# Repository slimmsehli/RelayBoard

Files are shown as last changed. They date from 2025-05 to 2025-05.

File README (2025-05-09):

🟢 4-Channel Relay Board with Opto-Isolation for Arduino/Raspberry Pi

This project is a modular, 4-channel relay control board designed for microcontrollers like **Arduino, Raspberry Pi, ESP32, etc.
The board features opto-isolation for electrical protection and safety, and is ideal for home automation, IoT, or industrial control applications.

---

## 📦 Features

- ✅ **4 independent relays** (SPDT type) – control AC/DC loads up to 250V AC / 30V DC
- ✅ **4 opto-isolated inputs** – control each relay with 3.3V or 5V logic
- ✅ **Load-side isolation** – added safety through PCB cutouts (drilled part under relay contacts)
- ✅ **Status indicator LEDs** – per-relay operation feedback
- ✅ Designed for **Arduino, Raspberry Pi, ESP8266, ESP32**, etc.
- ✅ Screw terminals for easy wiring of relays and power

---

## ⚙️ Technical Specs

| Feature | Description |
|---|---|
| **Relay type** | 5V SPDT |
| **Input voltage** | 5V logic compatible |
| **Isolation** | Optical + PCB drilled spacing |
| **Max switching** | 10A 250V AC / 10A 30V DC |
| **Board size** | 65mmx70mm |
| **Control headers**  | 4-pin input control (IN1–IN4) |
| **Load terminals** | NO, COM, NC per relay |

---

## 📌 Pinout

| Pin | Description |
|-----|---|
| IN1 | Control for Relay 1 |
| IN2 | Control for Relay 2 |
| IN3 | Control for Relay 3 |
| IN4 | Control for Relay 4 |
| VCC | Input side power (5V) |
| GND | Ground |

Each control input drives one relay via an optocoupler for full isolation.

---

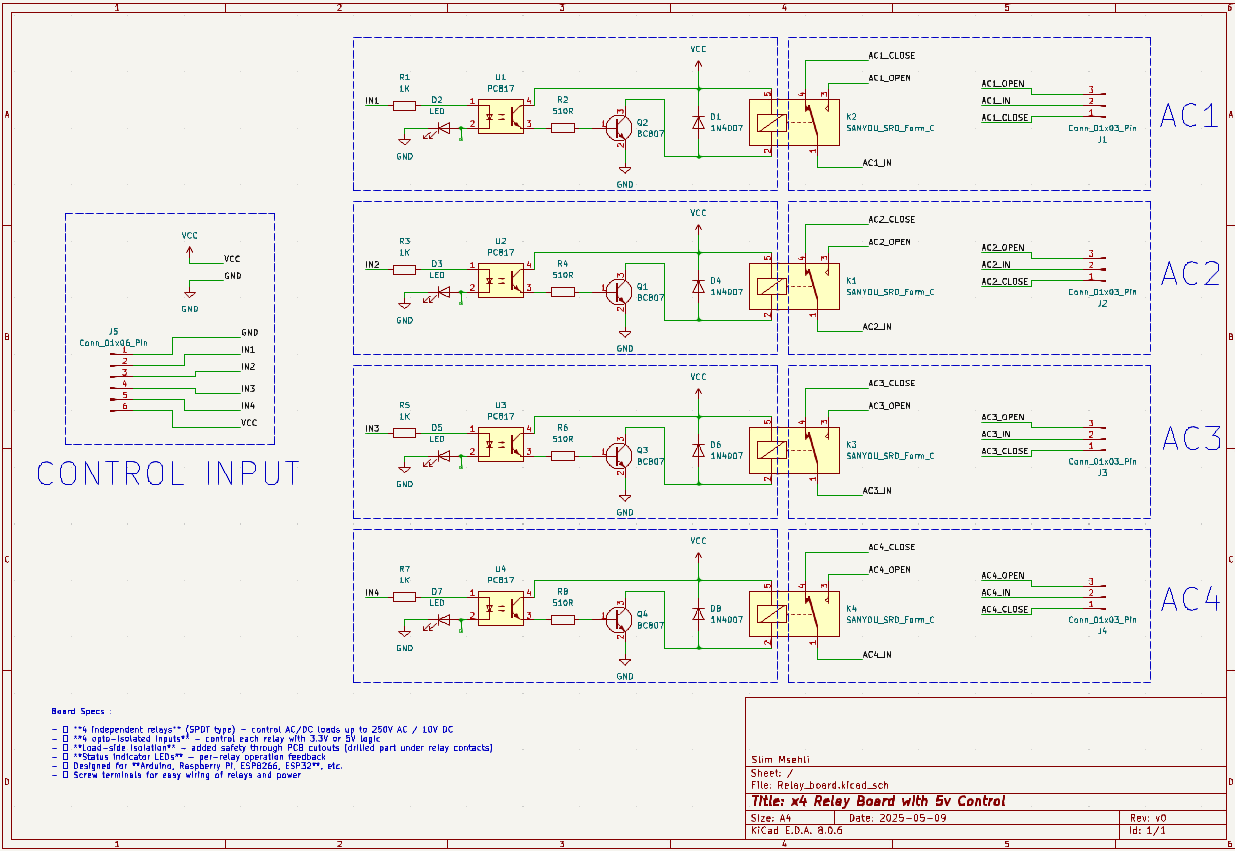
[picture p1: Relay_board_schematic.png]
Schematic circuit

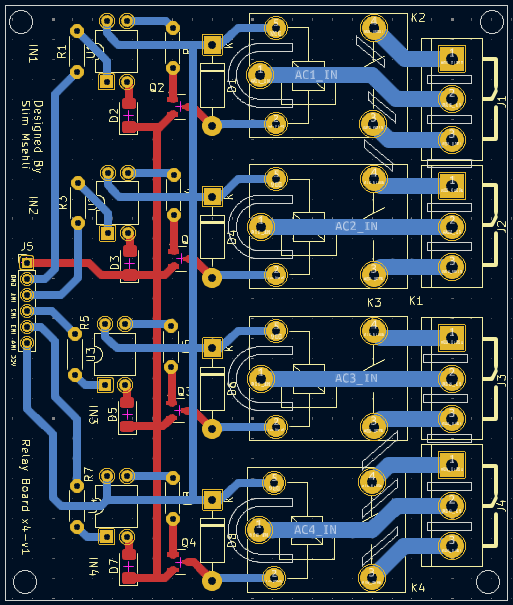
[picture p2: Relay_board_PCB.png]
PCB

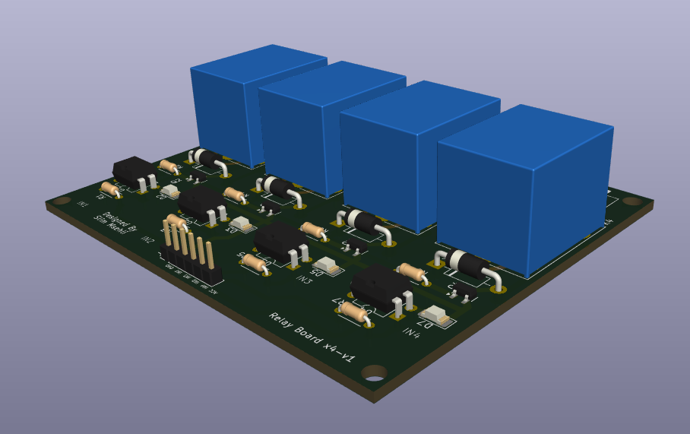
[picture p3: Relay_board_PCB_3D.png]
3D view


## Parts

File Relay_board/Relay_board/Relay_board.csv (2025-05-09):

Id | Designator | Footprint | Quantity | Designation | Supplier and ref
1 | R4,R6,R8,R2 | R_Axial_DIN0204_L3.6mm_D1.6mm_P5.08mm_Horizontal | 4 | 510R
2 | D3,D7,D5,D2 | LED_1206_3216Metric_Pad1.42x1.75mm_HandSolder | 4 | LED
3 | J2,J1,J4,J3 | TerminalBlock_bornier-3_P5.08mm | 4 | Conn_01x03_Pin
4 | Q1,Q4,Q2,Q3 | SOT-23 | 4 | BC807
5 | U4,U2,U1,U3 | DIP-4_W7.62mm | 4 | PC817
6 | K3,K2,K1,K4 | Relay_SPDT_SANYOU_SRD_Series_Form_C | 4 | SANYOU_SRD_Form_C
7 | D4,D8,D6,D1 | D_DO-35_SOD27_P7.62mm_Horizontal | 4 | 1N4007
8 | R1,R5,R7,R3 | R_Axial_DIN0204_L3.6mm_D1.6mm_P5.08mm_Horizontal | 4 | 1K
9 | J5 | PinHeader_1x06_P2.00mm_Vertical | 1 | Conn_01x06_Pin

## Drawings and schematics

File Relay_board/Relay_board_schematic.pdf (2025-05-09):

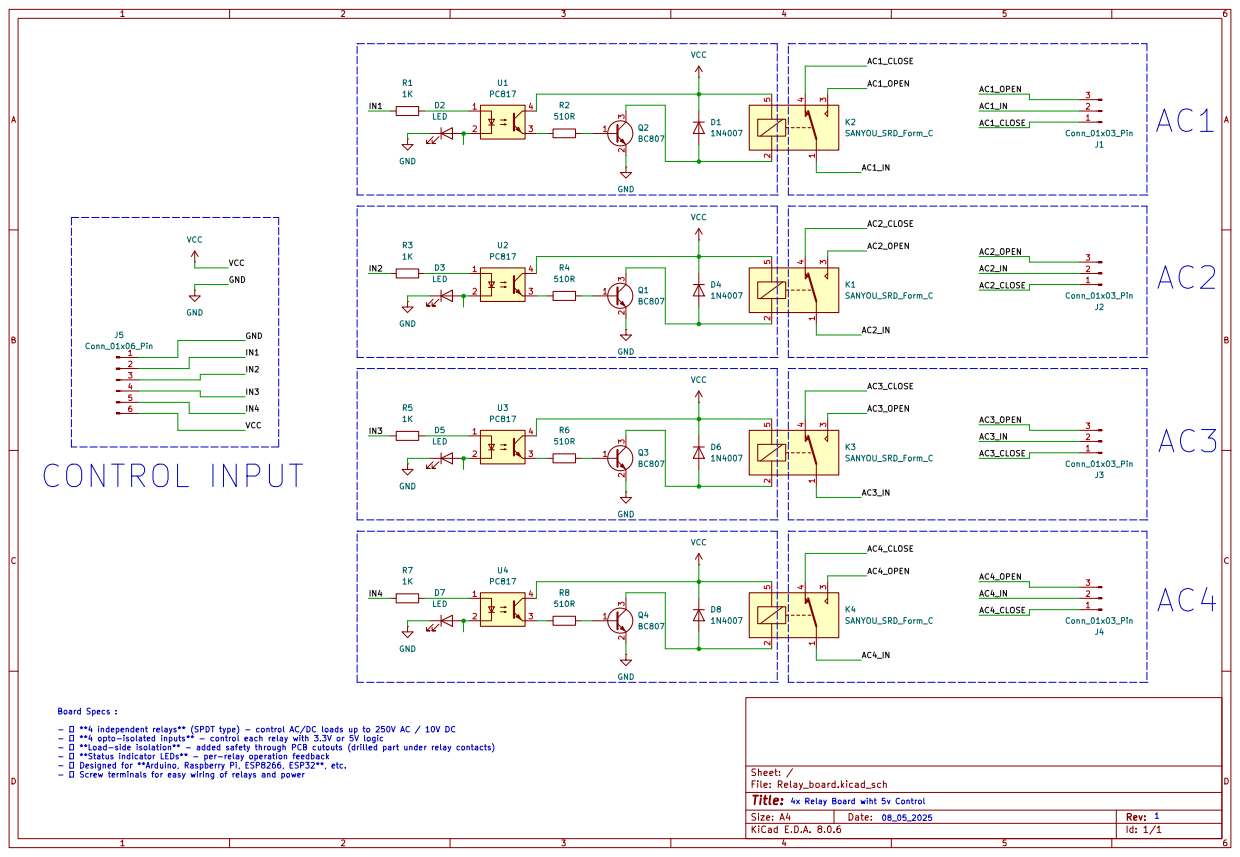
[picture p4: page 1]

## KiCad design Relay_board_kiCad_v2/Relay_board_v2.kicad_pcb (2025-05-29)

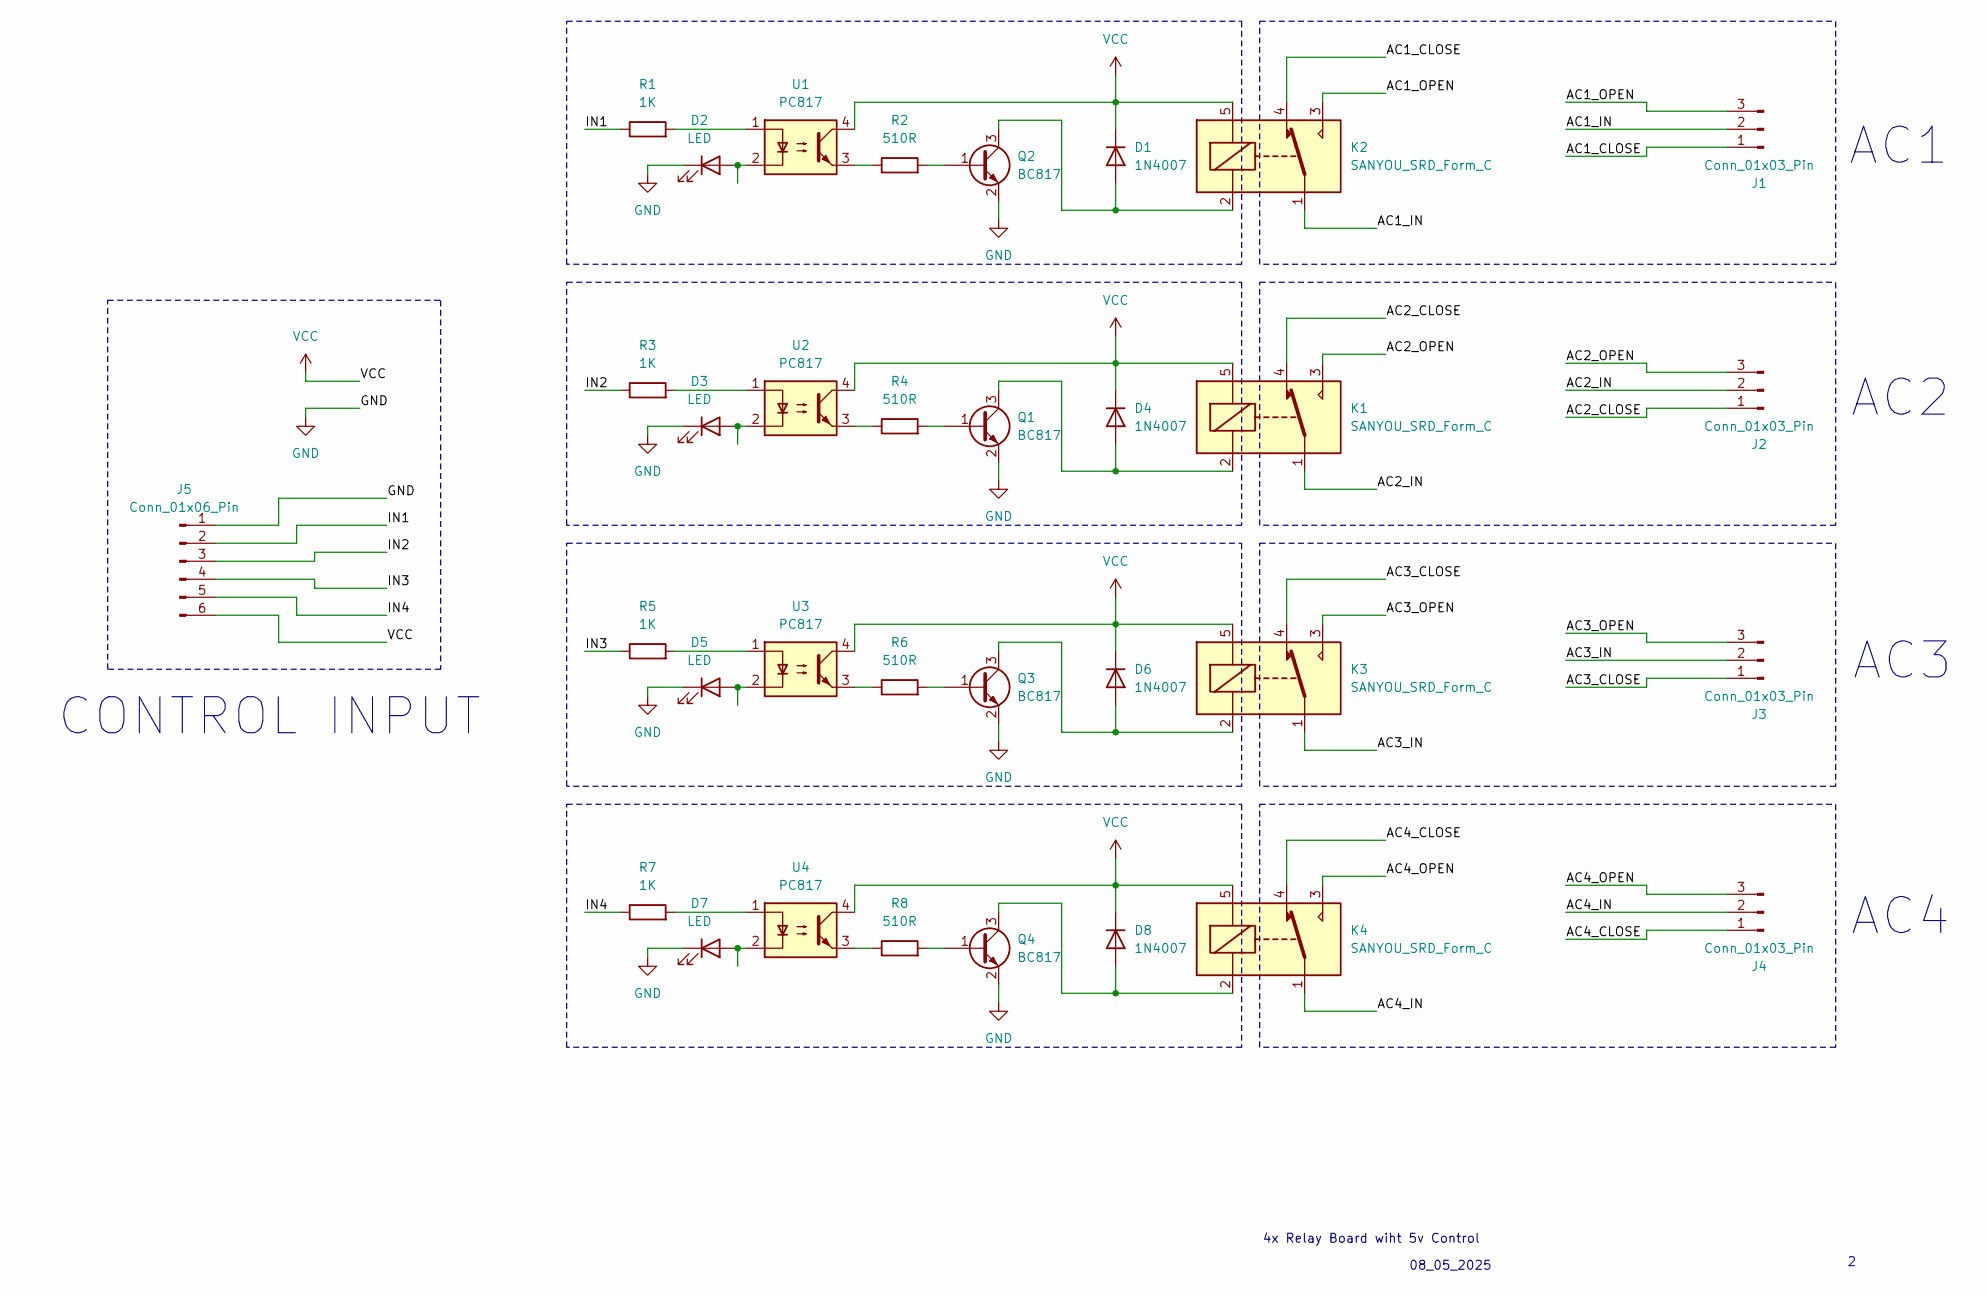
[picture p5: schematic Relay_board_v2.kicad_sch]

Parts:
D1, D4, D6, D8: 1N4007; D_DO-41_SOD81_P10.16mm_Horizontal
D2, D3, D5, D7: LED; LED_1206_3216Metric_Pad1.42x1.75mm_HandSolder
J1, J2, J3, J4: Conn_01x03_Pin; TerminalBlock_bornier-3_P5.08mm
J5: Conn_01x06_Pin; PinHeader_1x06_P2.54mm_Vertical
K1, K2, K3, K4: SANYOU_SRD_Form_C; Relay_SPDT_SANYOU_SRD_Series_Form_C
Q1, Q2, Q3, Q4: BC817; SOT-23
R1, R3, R5, R7: 1K; R_Axial_DIN0207_L6.3mm_D2.5mm_P10.16mm_Horizontal
R2, R4, R6, R8: 510R; R_Axial_DIN0207_L6.3mm_D2.5mm_P10.16mm_Horizontal
U1, U2, U3, U4: PC817; DIP-4_W7.62mm

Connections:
/AC1_CLOSE: J1.1, K2.4
/AC1_IN: J1.2, K2.1
/AC1_OPEN: J1.3, K2.3
/AC2_CLOSE: J2.1, K1.4
/AC2_IN: J2.2, K1.1
/AC2_OPEN: J2.3, K1.3
/AC3_CLOSE: J3.1, K3.4
/AC3_IN: J3.2, K3.1
/AC3_OPEN: J3.3, K3.3
/AC4_CLOSE: J4.1, K4.4
/AC4_IN: J4.2, K4.1
/AC4_OPEN: J4.3, K4.3
/IN1: J5.2, R1.1
/IN2: J5.3, R3.1
/IN3: J5.4, R5.1
/IN4: J5.5, R7.1
GND: D2.1 (K), D3.1 (K), D5.1 (K), D7.1 (K), J5.1, Q1.2 (E), Q2.2 (E), Q3.2 (E), Q4.2 (E)
unnamed: D1.2 (A), K2.2, Q2.3 (C)
unnamed: D2.2 (A), U1.2
unnamed: D3.2 (A), U2.2
unnamed: D4.2 (A), K1.2, Q1.3 (C)
unnamed: D5.2 (A), U3.2
unnamed: D6.2 (A), K3.2, Q3.3 (C)
unnamed: D7.2 (A), U4.2
unnamed: D8.2 (A), K4.2, Q4.3 (C)
unnamed: Q1.1 (B), R4.2
unnamed: Q2.1 (B), R2.2
unnamed: Q3.1 (B), R6.2
unnamed: Q4.1 (B), R8.2
unnamed: R1.2, U1.1
unnamed: R2.1, U1.3
unnamed: R3.2, U2.1
unnamed: R4.1, U2.3
unnamed: R5.2, U3.1
unnamed: R6.1, U3.3
unnamed: R7.2, U4.1
unnamed: R8.1, U4.3
VCC: D1.1 (K), D4.1 (K), D6.1 (K), D8.1 (K), J5.6, K1.5, K2.5, K3.5, K4.5, U1.4, U2.4, U3.4, U4.4

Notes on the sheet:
AC2
08_05_2025
AC3
4x Relay Board wiht 5v Control
CONTROL INPUT
AC1
AC4

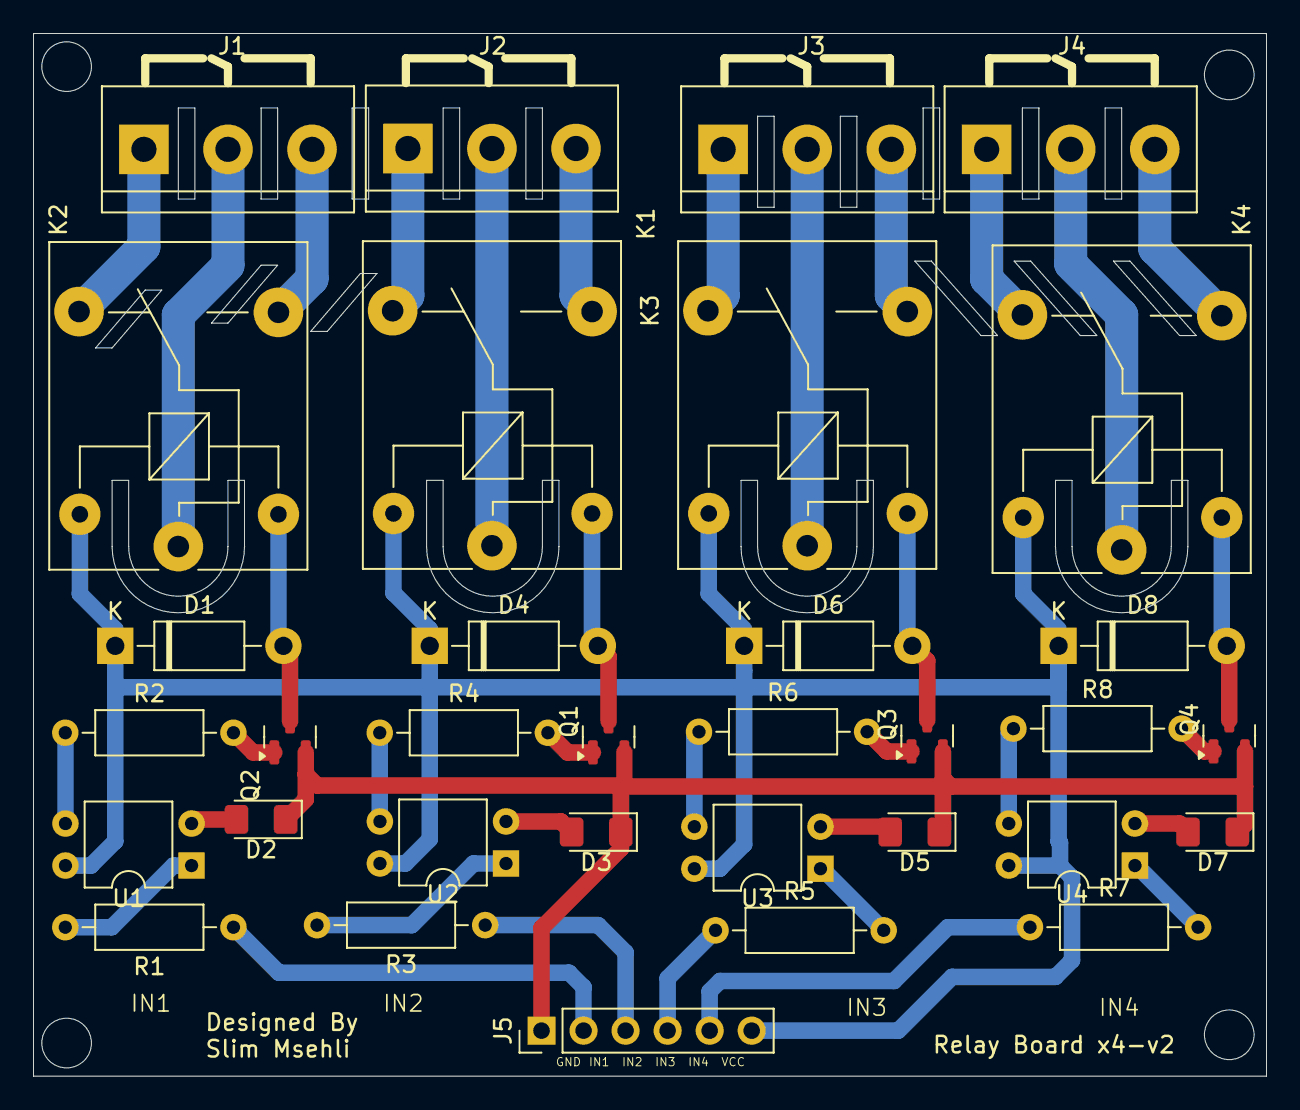
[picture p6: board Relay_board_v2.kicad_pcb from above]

Board: 2 copper layers, 74.5 x 63.0 mm, 33 parts (0 on the bottom side), 38 nets.

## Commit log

2025-05-29 Add files via upload
    version 2 of the board with resistor footprint replacement and minor text change
    [Relay_board_v2.kicad_pcb, Relay_board_v2.kicad_sch]
2025-05-29 Add files via upload
    pinout replacement
    [Relay_board_v2.kicad_pcb, Relay_board_v2.kicad_sch]
